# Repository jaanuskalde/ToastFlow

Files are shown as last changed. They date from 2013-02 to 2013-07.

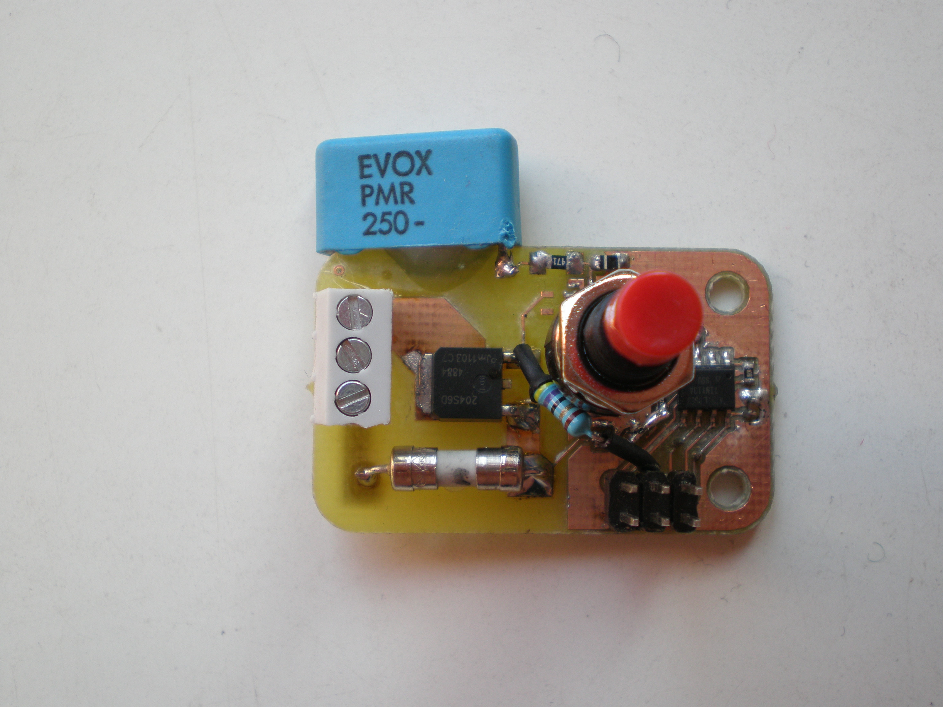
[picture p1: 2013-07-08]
media/P3260040.JPG

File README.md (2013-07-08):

ToastFlow
=========

Toaster reflow oven controller. Abandoned project due to some bugs and safety.

##Usage

Put boards with solder paste in the oven. Press the red button. When the led switches off you can take the boards out or something.

##About

Schematic is in KiCad. Schematic idea is from [ST app note "MICROCONTROLLER AND TRIACS ON THE 110/240V MAINS"](http://www.datasheetcatalog.org/datasheet/SGSThomsonMicroelectronics/mXxuyw.pdf). [Reflow profile](http://www.actel.com/documents/Solder_Reflow_LeadFree.pdf).

Uses weird temperature sensor. Heats boards to 150 degrees (1.3 kΩ, 3.143V, 41200), keeps there for 1m 10s and heats it up to 220 degrees (1.8 kΩ, 2.75V, 36000) 1m 30s.

| Part | Value |Pack | Farnell Code  |
|---|---|-----|---|
|Attiny13 | | SO8 |1704567|
|Temp sensor| |DO-34|1672407|
|The button |||1634684|
|Screw terminal|3x3.5 mm||3882627|
|TRIAC|4A|DPAK|1757884|
|X1 capacitor|100 nF||1907253|
|Fuse|4A||1829558|
|Diode|||8150206|
|Reservoir capacitor|100 µF|5mm|9452354|
|Zener diode|5V1|SOD323|8735735|

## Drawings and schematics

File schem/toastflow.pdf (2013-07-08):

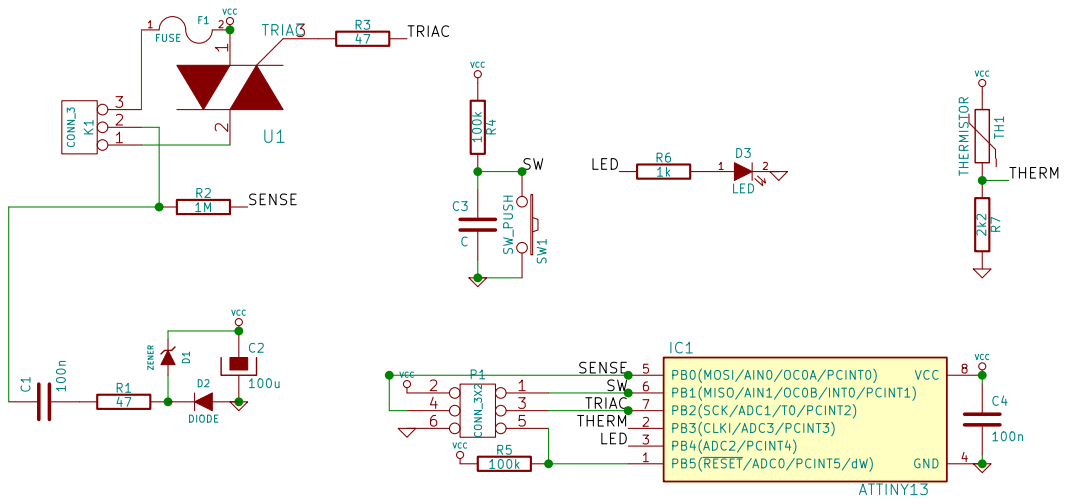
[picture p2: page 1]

C Sheet: /home/jaanus/Dropbox/projektid/reflow/ToastFlow/schem/toastflow.sch File: Title:

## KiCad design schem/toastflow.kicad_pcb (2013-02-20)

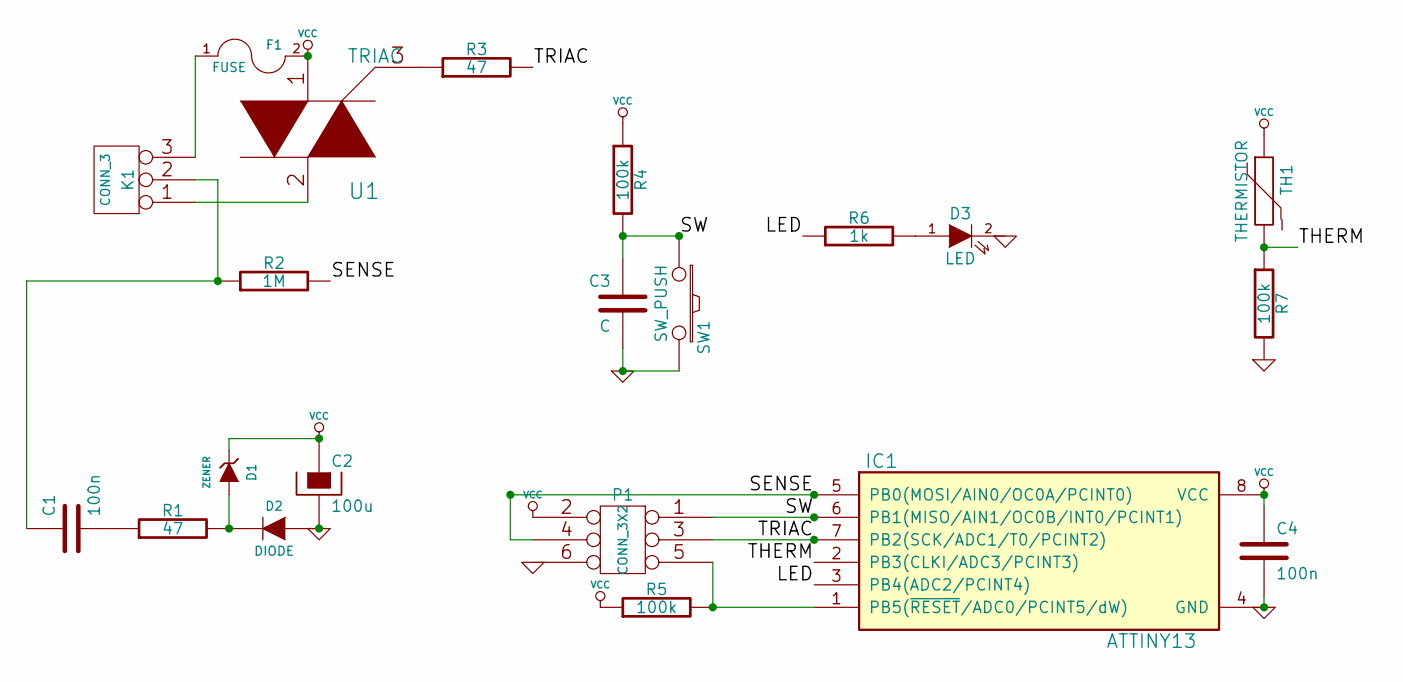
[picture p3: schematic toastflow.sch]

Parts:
C1, C4: 100n
C2: 100u
C3: C
D1: ZENER
D2: DIODE
D3: LED
F1: FUSE
IC1: ATTINY13; DIP8
K1: CONN_3
P1: CONN_3X2
R1, R3: 47
R2: 1M
R4, R5, R7: 100k
R6: 1k
SW1: SW_PUSH
TH1: THERMISTOR
U1: TRIAC

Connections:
/LED: IC1.3 (PB4(ADC2/PCINT4)), R6.1
/SENSE: IC1.5 (PB0(MOSI/AIN0/OC0A/PCINT0)), P1.4, R2.2
/SW: C3.1, IC1.6 (PB1(MISO/AIN1/OC0B/INT0/PCINT1)), P1.1, R4.2, SW1.1
/THERM: IC1.2 (PB3(CLKI/ADC3/PCINT3)), R7.1, TH1.2
/TRIAC: IC1.7 (PB2(SCK/ADC1/T0/PCINT2)), P1.3, R3.2
GND: C2.2, C3.2, C4.2, D2.2 (A), D3.2 (K), IC1.4 (GND), P1.6, R7.2, SW1.2
unnamed: D1.2 (A), D2.1 (K), R1.2
unnamed: C1.2, R1.1
unnamed: C1.1, K1.2 (PM), R2.1
unnamed: R3.1, U1.3
unnamed: K1.1, U1.2
unnamed: F1.1, K1.3
unnamed: D3.1 (A), R6.2
unnamed: IC1.1 (PB5(~RESET~/ADC0/PCINT5/dW)), P1.5, R5.2
VCC: C2.1, C4.1, D1.1 (K), F1.2, IC1.8 (VCC), P1.2, R4.1, R5.1, TH1.1, U1.1

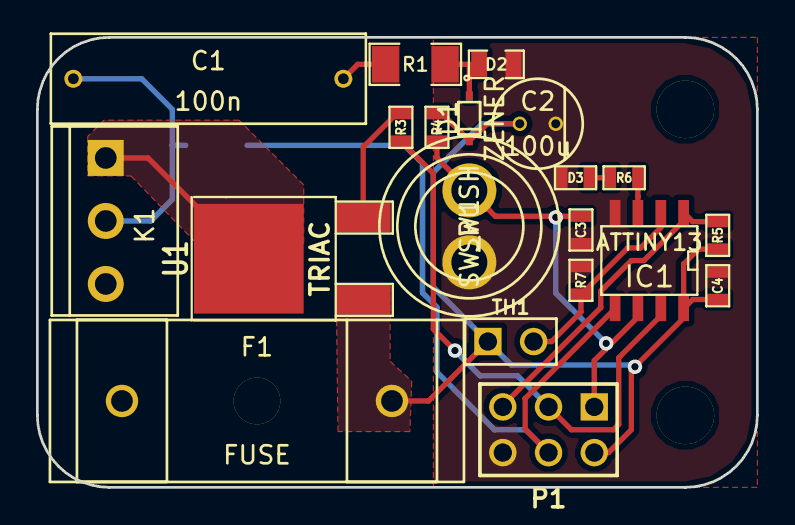
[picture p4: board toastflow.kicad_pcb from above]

Board: 2 copper layers, 40.0 x 25.0 mm, 23 parts (1 on the bottom side), 15 nets.

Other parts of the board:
drill_3.2mm, drill_3.2mm#2: VAL**; drill_3.2mm

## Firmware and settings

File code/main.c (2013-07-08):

#define F_CPU 1200000UL

// AVR includes
#include <avr/interrupt.h>
#include <avr/io.h>
#include <util/delay.h>

#define average(old, new) ( (new >> 2)+(old - (old >> 2)) )

#define SENSE 0x01
#define SWITCH 0x02
#define TRIAC 0x04
#define THERMISTOR 0x08
#define LED 0x10;

int main()
{

	cli();	// Clear interrupts
	PORTB |= TRIAC; //Turn off the Triac
	DDRB = 0b00010100;

	//ADC conf
	ADMUX = (1<<ADLAR) | (1<<MUX1) | (1<<MUX0);
	ADCSRA = (1<<ADEN) | (1<<ADPS1) | (1<<ADPS0);
	sei();//Enable interrupts
	
	enum 
	{
		OFF, 
		PREHEAT, 
		REFLOW
	} state = OFF;

	uint8_t last_sense = 0;
	uint16_t counter = 0;
	uint16_t last_voltage = 0;
	uint8_t heater_request = 0;

	//Application loop
	while (1)
	{
		//Wait for button pressing 
		while (SWITCH & PINB)
		{
			counter ++;
			if (counter & 0x10) PORTB |= LED else PORTB &= ~LED;
			_delay_ms(4);
		}

		state = PREHEAT;
		PORTB |= LED;
		counter = 0;

		while (state != OFF)
		{
			if (PINB & SENSE)
			{
				last_sense = 1;
			}
			else //on falling edge
			{
				if (last_sense)//turn on for this whole cycle
				{
					if (heater_request)
					{
						PORTB &= ~TRIAC;
						_delay_us(50);
						PORTB |= TRIAC;
						_delay_ms(10);
						PORTB &= ~TRIAC;
						_delay_us(50);
						PORTB |= TRIAC;
					}
					else
					{
						_delay_ms(11);
					}
					counter ++;
					if (state == PREHEAT) PORTB ^= LED; //blink the led
				}
				last_sense = 0;
			}
			//about 19ms to do measurement and user interaction
			
			ADCSRA |= (1<<ADSC); //start conversion
			while (ADCSRA & (1<<ADSC));//wait it to complete
			last_voltage = average(last_voltage, ADC);//get the content

			switch(state)
			{
				case OFF:
					PORTB &= ~LED;
					break;
				case PREHEAT:
					if (last_voltage < 41200) heater_request = 0; else heater_request = 1;
					if (counter > 3500)
					{
						state = REFLOW;
						PORTB |= LED;
						counter = 0;
					}
					break;
				case REFLOW:
					if (last_voltage < 36000) heater_request = 0; else heater_request = 1;
					if (counter > 4500)
					{
						state = OFF;
						counter = 0;
						heater_request = 0;
					}
					break;
			}
			
			_delay_ms(1);
		}
	}
}

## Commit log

2013-02-18 Routed ver1 of PCB
    [toastflow.kicad_pcb, toastflow.sch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]
2013-02-20 Blank code
    [toastflow.kicad_pcb]
2013-02-20 Fixed triac pin.
    [toastflow.kicad_pcb, toastflow.sch]
2013-03-10 Real code, some bugs.
    [main.c]
2013-03-10 Component fix
    [toastflow.sch]
